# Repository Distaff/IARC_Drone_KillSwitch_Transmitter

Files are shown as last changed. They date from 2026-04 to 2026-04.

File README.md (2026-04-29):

# Killswitch for IARC Hat for CMDB
## PCB Design

Board layout:
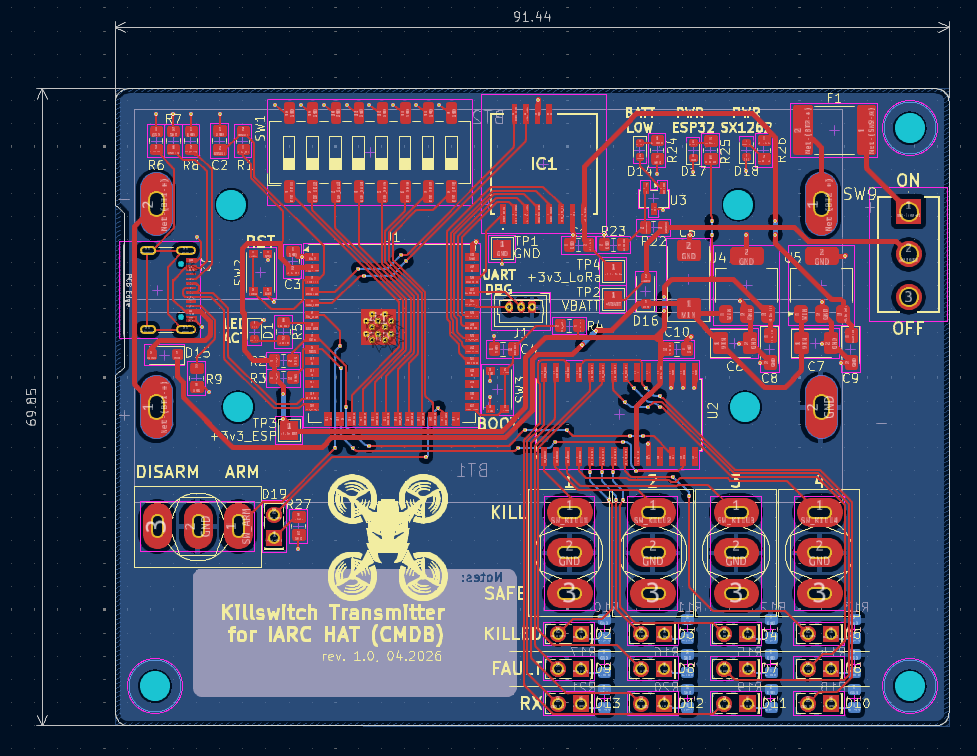
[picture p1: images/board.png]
Board layout


3D render:
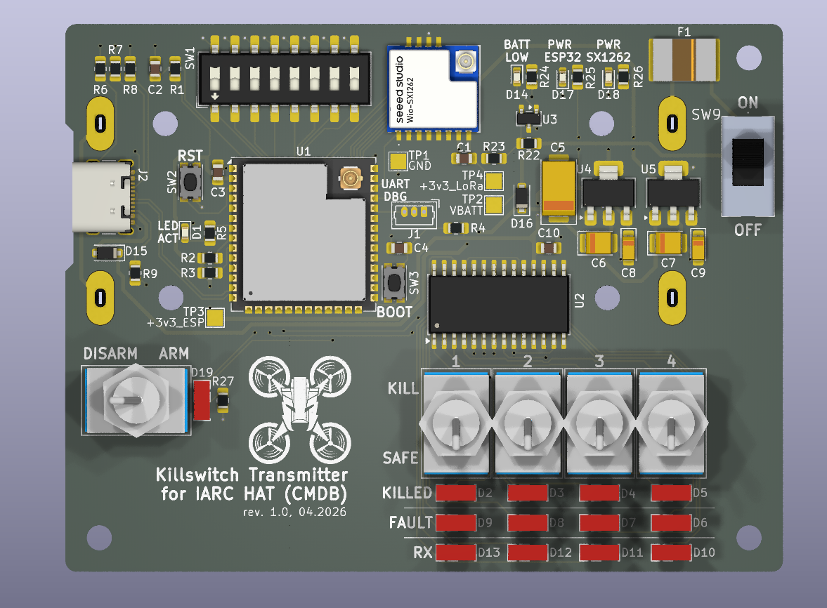
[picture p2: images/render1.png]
3D render front 3D render - front

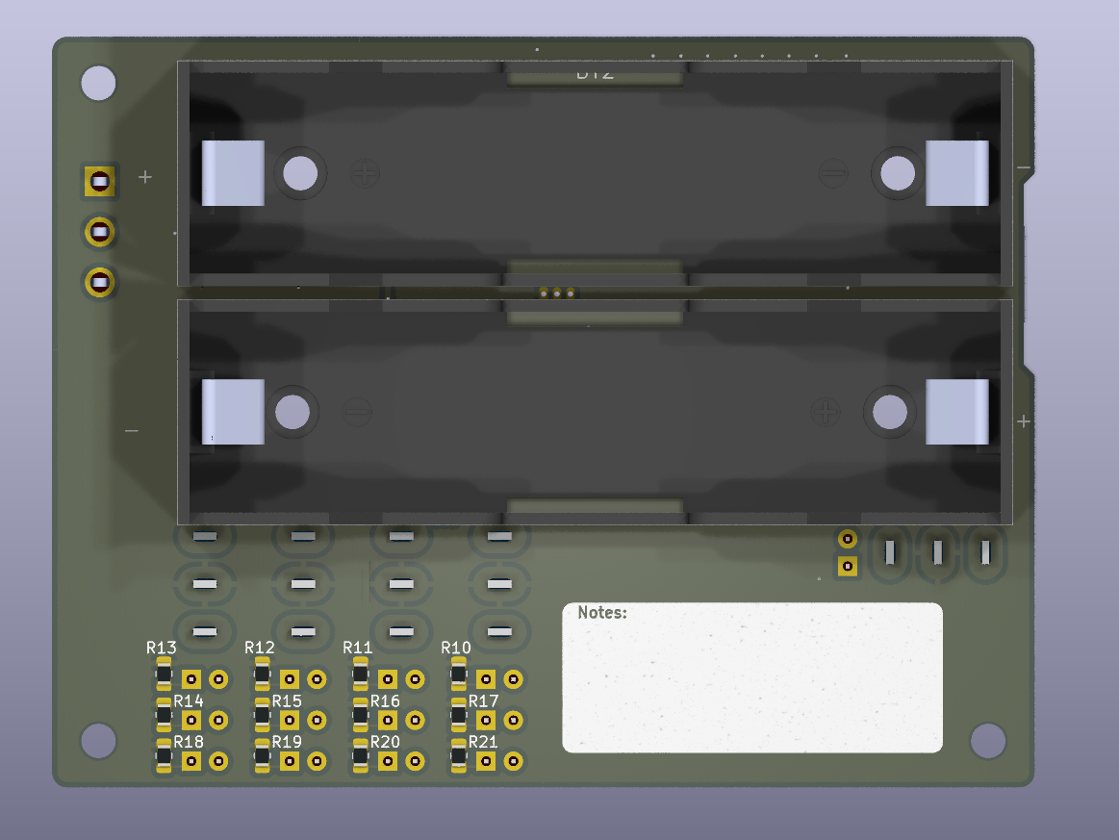
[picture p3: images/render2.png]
3D render back 3D render - back


## Usage
- Broadcast killing signal for drones using IARC CMDB hat or other LoRa-based killswitch
- Serve as LoRa packet grabber (by connecting to PC through UART

Board can be powered either from 2x 18650 cells or directly from USB-C (if host provides enough power).
No built-in undervoltage protection circuit is present, except for a warning LED.

## Authors
- Szymon Konopka (PCB Design)
- Piotr Kądziela (schematic design and PCB review)

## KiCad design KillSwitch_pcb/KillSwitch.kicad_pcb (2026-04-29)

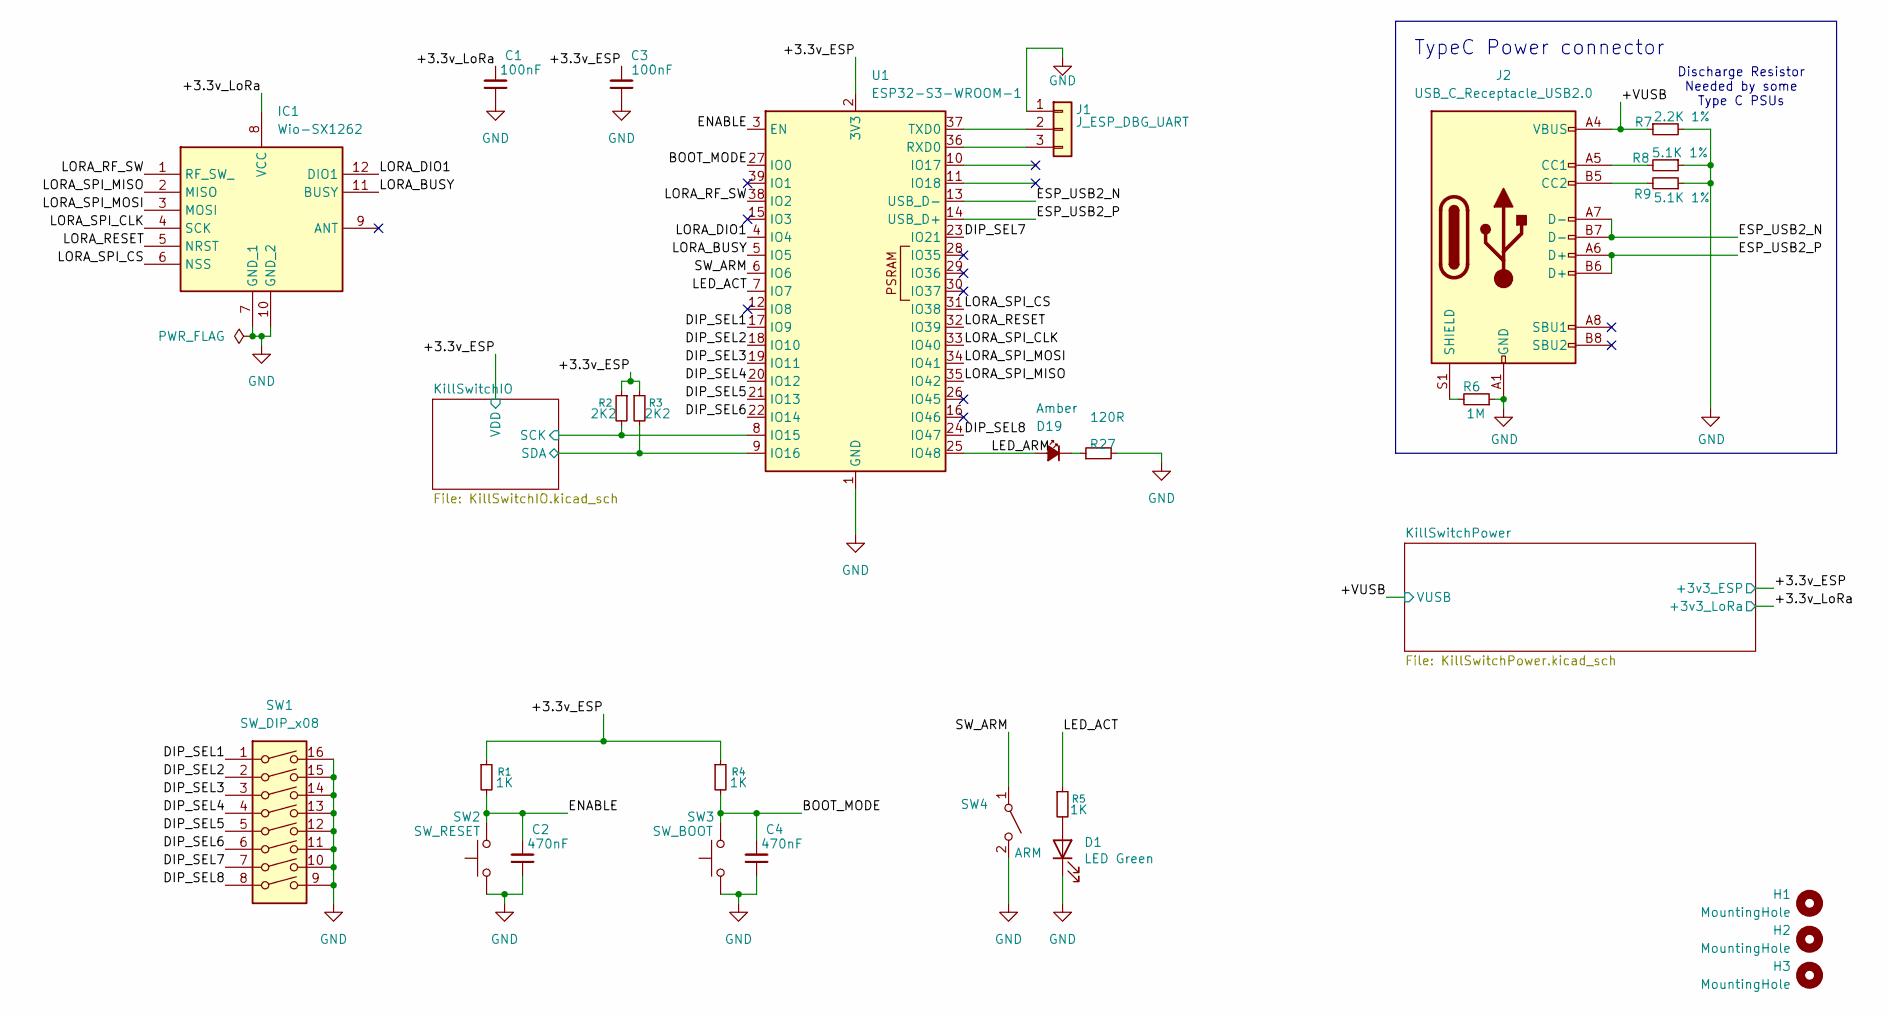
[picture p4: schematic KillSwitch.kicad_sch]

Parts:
C1, C3: 100nF; C_0805_2012Metric_Pad1.18x1.45mm_HandSolder
C2, C4: 470nF; C_0805_2012Metric_Pad1.18x1.45mm_HandSolder
D1: LED Green; LED_0603_1608Metric; Part Description Green 572nm LED Indication - Discrete 2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
D19: Amber; LED_Rectangular_W5.0mm_H2.0mm
H1, H2, H3: MountingHole; MountingHole_3.2mm_M3_DIN965
IC1: Wio-SX1262; Mouser Part Number 713-114993390
J1: J_ESP_DBG_UART; Molex_PicoBlade_53047-0310_1x03_P1.25mm_Vertical; Part Description Pin Header, Vertical, Signal, Wire-to-B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
J2: USB_C_Receptacle_USB2.0; USB_C_Receptacle_GCT_USB4105-xx-A_16P_TopMnt_Horizontal; Part Description USBC USB2 data and power connector
R1, R4, R5: 1K; R_0805_2012Metric_Pad1.20x1.40mm_HandSolder
R2, R3: 2K2; R_0805_2012Metric_Pad1.20x1.40mm_HandSolder
R6: 1M; R_0805_2012Metric_Pad1.20x1.40mm_HandSolder; Part Description Resistor 5.1K 1% 63mW
R7: 2.2K 1%; R_0805_2012Metric_Pad1.20x1.40mm_HandSolder; Part Description Resistor 2.2K 1% 63mW
R8, R9: 5.1K 1%; R_0805_2012Metric_Pad1.20x1.40mm_HandSolder; Part Description Resistor 5.1K 1% 63mW
R27: 120R; R_0805_2012Metric_Pad1.20x1.40mm_HandSolder
SW1: SW_DIP_x08; SW_DIP_SPSTx08_Slide_6.7x21.88mm_W8.61mm_P2.54mm_LowProfile
SW2: SW_RESET; SW_Push_1P1T_NO_CK_KMR2; Part Description Tactile Switch, KMR 2 Series, Top Actua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
SW3: SW_BOOT; SW_Push_1P1T_NO_CK_KMR2; Part Description Tactile Switch, KMR 2 Series, Top Actua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
SW4: ARM; SW_Toggle_Blue_wSlots
U1: ESP32-S3-WROOM-1; ESP32-S3-WROOM-1U

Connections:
/+3.3v_ESP: C3.2, R1.1, R2.1, R3.1, R4.1, U1.2 (3V3); also elsewhere on the board
/+3.3v_LoRa: C1.2, IC1.8 (VCC); also elsewhere on the board
/+VUSB: J2.A4 (VBUS), J2.A9 (VBUS), J2.B4 (VBUS), J2.B9 (VBUS), R7.1; also elsewhere on the board
/BOOT_MODE: C4.2, R4.2, SW3.2, U1.27 (IO0)
/DIP_SEL1: SW1.1, U1.17 (IO9)
/DIP_SEL2: SW1.2, U1.18 (IO10)
/DIP_SEL3: SW1.3, U1.19 (IO11)
/DIP_SEL4: SW1.4, U1.20 (IO12)
/DIP_SEL5: SW1.5, U1.21 (IO13)
/DIP_SEL6: SW1.6, U1.22 (IO14)
/DIP_SEL7: SW1.7, U1.23 (IO21)
/DIP_SEL8: SW1.8, U1.24 (IO47)
/ENABLE: C2.2, R1.2, SW2.2, U1.3 (EN)
/ESP_USB2_N: J2.A7 (D-), J2.B7 (D-), U1.13 (USB_D-)
/ESP_USB2_P: J2.A6 (D+), J2.B6 (D+), U1.14 (USB_D+)
/KillSwitchIO/SCK: R2.2, U1.8 (IO15); also elsewhere on the board
/KillSwitchIO/SDA: R3.2, U1.9 (IO16); also elsewhere on the board
/LED_ACT: R5.1, U1.7 (IO7)
/LED_ARM: D19.2 (A), U1.25 (IO48)
/LORA_BUSY: IC1.11 (BUSY), U1.5 (IO5)
/LORA_DIO1: IC1.12 (DIO1), U1.4 (IO4)
/LORA_RESET: IC1.5 (NRST), U1.32 (IO39)
/LORA_RF_SW: IC1.1 (RF_SW_), U1.38 (IO2)
/LORA_SPI_CLK: IC1.4 (SCK), U1.33 (IO40)
/LORA_SPI_CS: IC1.6 (NSS), U1.31 (IO38)
/LORA_SPI_MISO: IC1.2 (MISO), U1.35 (IO42)
/LORA_SPI_MOSI: IC1.3 (MOSI), U1.34 (IO41)
/SW_ARM: SW4.1 (A), U1.6 (IO6)
GND: C1.1, C2.1, C3.1, C4.1, D1.1 (K), IC1.7 (GND_1), IC1.10 (GND_2), J1.1, J2.A1 (GND), J2.A12 (GND), J2.B1 (GND), J2.B12 (GND), R6.1, R7.2, R8.1, R9.1, R27.2, SW1.9, SW1.10, SW1.11, SW1.12, SW1.13, SW1.14, SW1.15, SW1.16, SW2.1, SW3.1, SW4.2 (B), U1.1 (GND), U1.40 (GND), U1.41 (GND); also elsewhere on the board
unnamed: D1.2 (A), R5.2
unnamed: D19.1 (K), R27.1
unnamed: J1.2, U1.37 (TXD0)
unnamed: J1.3, U1.36 (RXD0)
unnamed: J2.A5 (CC1), R8.2
unnamed: J2.B5 (CC2), R9.2
unnamed: J2.S1 (SHIELD), R6.2

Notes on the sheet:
Discharge Resistor Needed by some Type C PSUs
TypeC Power connector

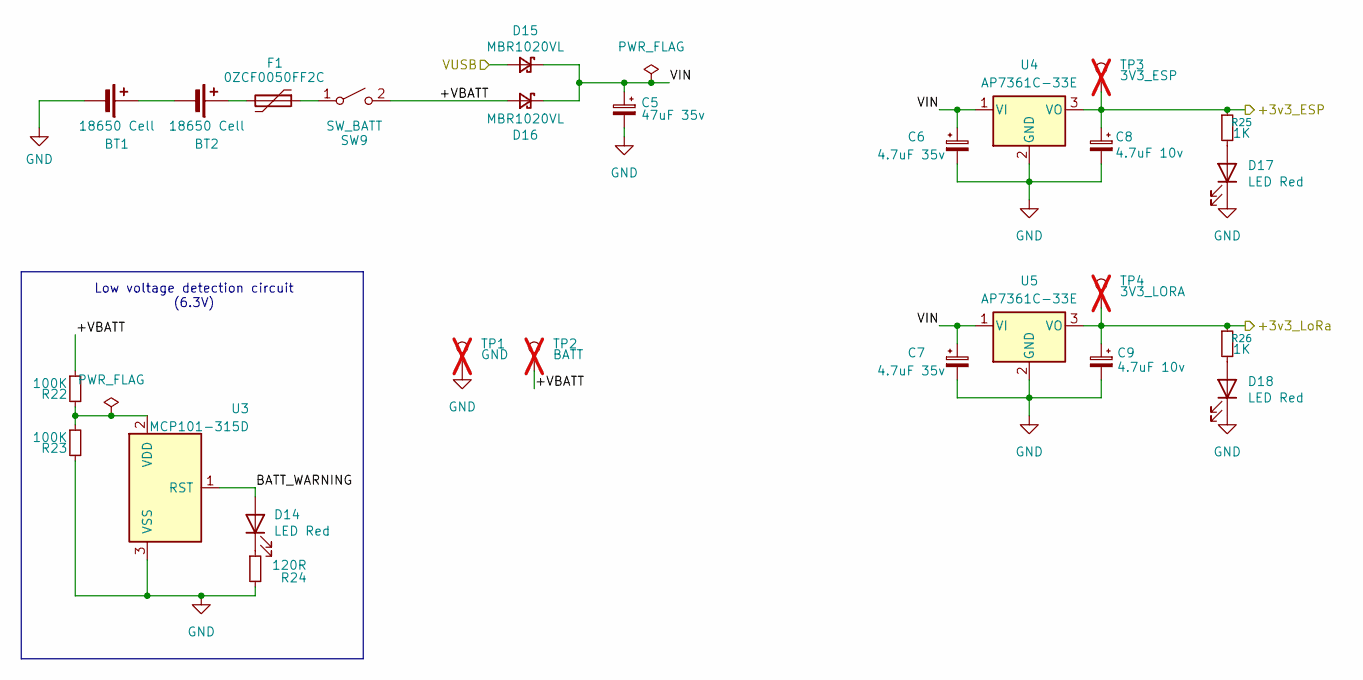
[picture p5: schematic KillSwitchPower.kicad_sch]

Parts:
BT1, BT2: 18650 Cell; BAT_BH-18650-PC
C5: 47uF 35v; CP_EIA-7343-31_Kemet-D_HandSolder
C6, C7: 4.7uF 35v; CP_EIA-3528-21_Kemet-B_HandSolder
C8, C9: 4.7uF 10v; CP_EIA-3216-18_Kemet-A_HandSolder
D14, D17, D18: LED Red; LED_0603_1608Metric; Part Description Red 620nm LED Indication - Discrete 2.2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
D15, D16: MBR1020VL; D_SOD-123F
F1: 0ZCF0050FF2C; Fuse_2920_7451Metric_Pad2.10x5.45mm_HandSolder
R22, R23: 100K; R_0805_2012Metric_Pad1.20x1.40mm_HandSolder
R24: 120R; R_0805_2012Metric_Pad1.20x1.40mm_HandSolder
R25, R26: 1K; R_0805_2012Metric_Pad1.20x1.40mm_HandSolder
SW9: SW_BATT; SL19121
TP1: GND; TestPoint_Pad_2.0x2.0mm; Part Description Test point; not fitted
TP2: BATT; TestPoint_Pad_2.0x2.0mm; Part Description Test point; not fitted
TP3: 3V3_ESP; TestPoint_Pad_2.0x2.0mm; Part Description Test point; not fitted
TP4: 3V3_LORA; TestPoint_Pad_2.0x2.0mm; Part Description Test point; not fitted
U3: MCP101-315D; SOT-23-3
U4, U5: AP7361C-33E; SOT-223-3_TabPin2; Part Description LDO, FIXED, 3.3V, 1A, -40 TO 85DEG C

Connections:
/+3.3v_ESP: C8.1, R25.1, TP3.1, U4.3 (VO); also elsewhere on the board
/+3.3v_LoRa: C9.1, R26.1, TP4.1, U5.3 (VO); also elsewhere on the board
/+VUSB: D15.2 (A); also elsewhere on the board
/KillSwitchPower/+VBATT: D16.2 (A), R22.1, SW9.2 (B), TP2.1
/KillSwitchPower/BATT_WARNING: D14.2 (A), U3.1 (RST)
/KillSwitchPower/VIN: C5.1, C6.1, C7.1, D15.1 (K), D16.1 (K), U4.1 (VI), U5.1 (VI)
GND: BT1.2 (-), C5.2, C6.2, C7.2, C8.2, C9.2, D17.1 (K), D18.1 (K), R23.2, R24.2, TP1.1, U3.3 (VSS), U4.2 (GND), U5.2 (GND); also elsewhere on the board
unnamed: BT1.1 (+), BT2.2 (-)
unnamed: BT2.1 (+), F1.2
unnamed: D14.1 (K), R24.1
unnamed: D17.2 (A), R25.2
unnamed: D18.2 (A), R26.2
unnamed: F1.1, SW9.1 (A)
unnamed: R22.2, R23.1, U3.2 (VDD)

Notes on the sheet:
Low voltage detection circuit (6.3V)

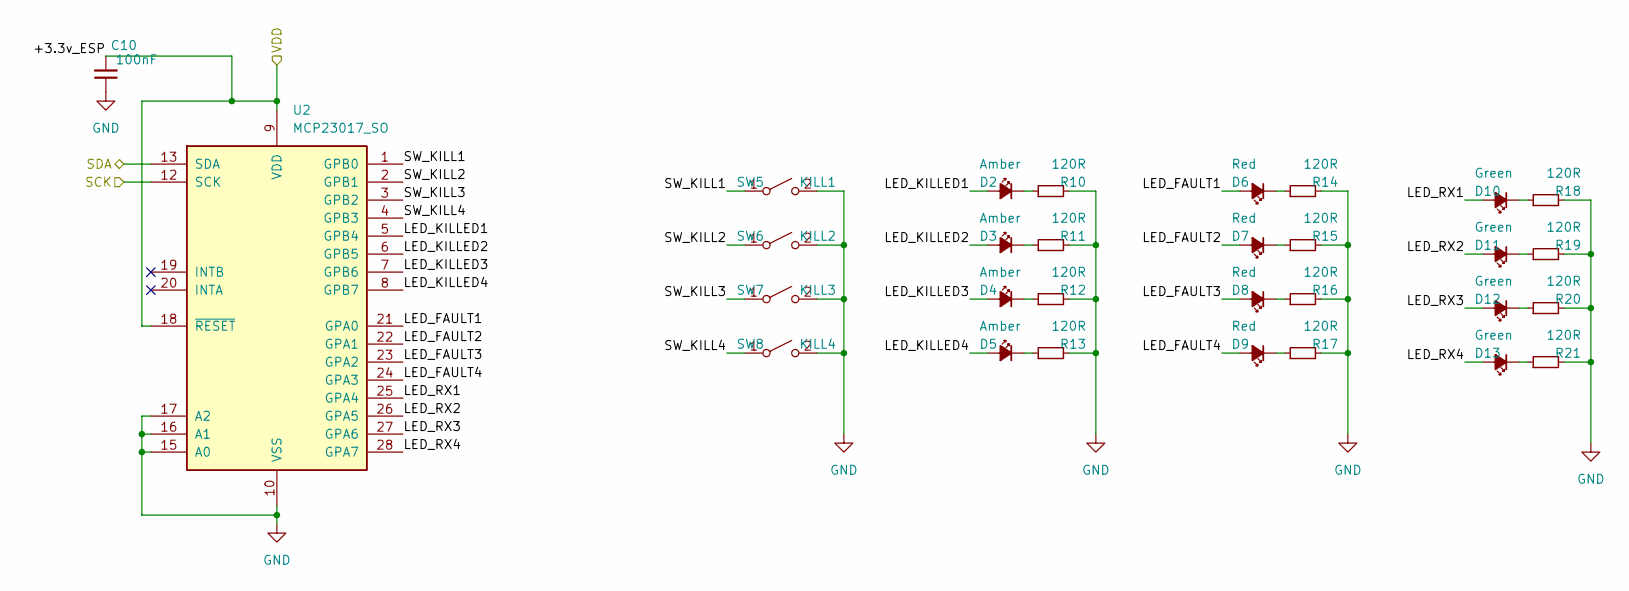
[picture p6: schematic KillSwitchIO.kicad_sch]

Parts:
C10: 100nF; C_0805_2012Metric_Pad1.18x1.45mm_HandSolder
D2, D3, D4, D5: Amber; LED_Rectangular_W5.0mm_H2.0mm
D6, D7, D8, D9: Red; LED_Rectangular_W5.0mm_H2.0mm
D10, D11, D12, D13: Green; LED_Rectangular_W5.0mm_H2.0mm
R10, R11, R12, R13, R14, R15, R16, R17, R18, R19, R20, R21: 120R; R_0805_2012Metric_Pad1.20x1.40mm_HandSolder
SW5: KILL1; SW_Toggle_Blue_wSlots
SW6: KILL2; SW_Toggle_Blue_wSlots
SW7: KILL3; SW_Toggle_Blue_wSlots
SW8: KILL4; SW_Toggle_Blue_wSlots
U2: MCP23017_SO; SOIC-28W_7.5x17.9mm_P1.27mm

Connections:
/+3.3v_ESP: C10.2, U2.9 (VDD), U2.18 (~RESET); also elsewhere on the board
/KillSwitchIO/LED_FAULT1: D6.2 (A), U2.21 (GPA0)
/KillSwitchIO/LED_FAULT2: D7.2 (A), U2.22 (GPA1)
/KillSwitchIO/LED_FAULT3: D8.2 (A), U2.23 (GPA2)
/KillSwitchIO/LED_FAULT4: D9.2 (A), U2.24 (GPA3)
/KillSwitchIO/LED_KILLED1: D2.2 (A), U2.5 (GPB4)
/KillSwitchIO/LED_KILLED2: D3.2 (A), U2.6 (GPB5)
/KillSwitchIO/LED_KILLED3: D4.2 (A), U2.7 (GPB6)
/KillSwitchIO/LED_KILLED4: D5.2 (A), U2.8 (GPB7)
/KillSwitchIO/LED_RX1: D10.2 (A), U2.25 (GPA4)
/KillSwitchIO/LED_RX2: D11.2 (A), U2.26 (GPA5)
/KillSwitchIO/LED_RX3: D12.2 (A), U2.27 (GPA6)
/KillSwitchIO/LED_RX4: D13.2 (A), U2.28 (GPA7)
/KillSwitchIO/SCK: U2.12 (SCK); also elsewhere on the board
/KillSwitchIO/SDA: U2.13 (SDA); also elsewhere on the board
/KillSwitchIO/SW_KILL1: SW5.1 (A), U2.1 (GPB0)
/KillSwitchIO/SW_KILL2: SW6.1 (A), U2.2 (GPB1)
/KillSwitchIO/SW_KILL3: SW7.1 (A), U2.3 (GPB2)
/KillSwitchIO/SW_KILL4: SW8.1 (A), U2.4 (GPB3)
GND: C10.1, R10.2, R11.2, R12.2, R13.2, R14.2, R15.2, R16.2, R17.2, R18.2, R19.2, R20.2, R21.2, SW5.2 (B), SW6.2 (B), SW7.2 (B), SW8.2 (B), U2.10 (VSS), U2.15 (A0), U2.16 (A1), U2.17 (A2); also elsewhere on the board
unnamed: D2.1 (K), R10.1
unnamed: D3.1 (K), R11.1
unnamed: D4.1 (K), R12.1
unnamed: D5.1 (K), R13.1
unnamed: D6.1 (K), R14.1
unnamed: D7.1 (K), R15.1
unnamed: D8.1 (K), R16.1
unnamed: D9.1 (K), R17.1
unnamed: D10.1 (K), R18.1
unnamed: D11.1 (K), R19.1
unnamed: D12.1 (K), R20.1
unnamed: D13.1 (K), R21.1

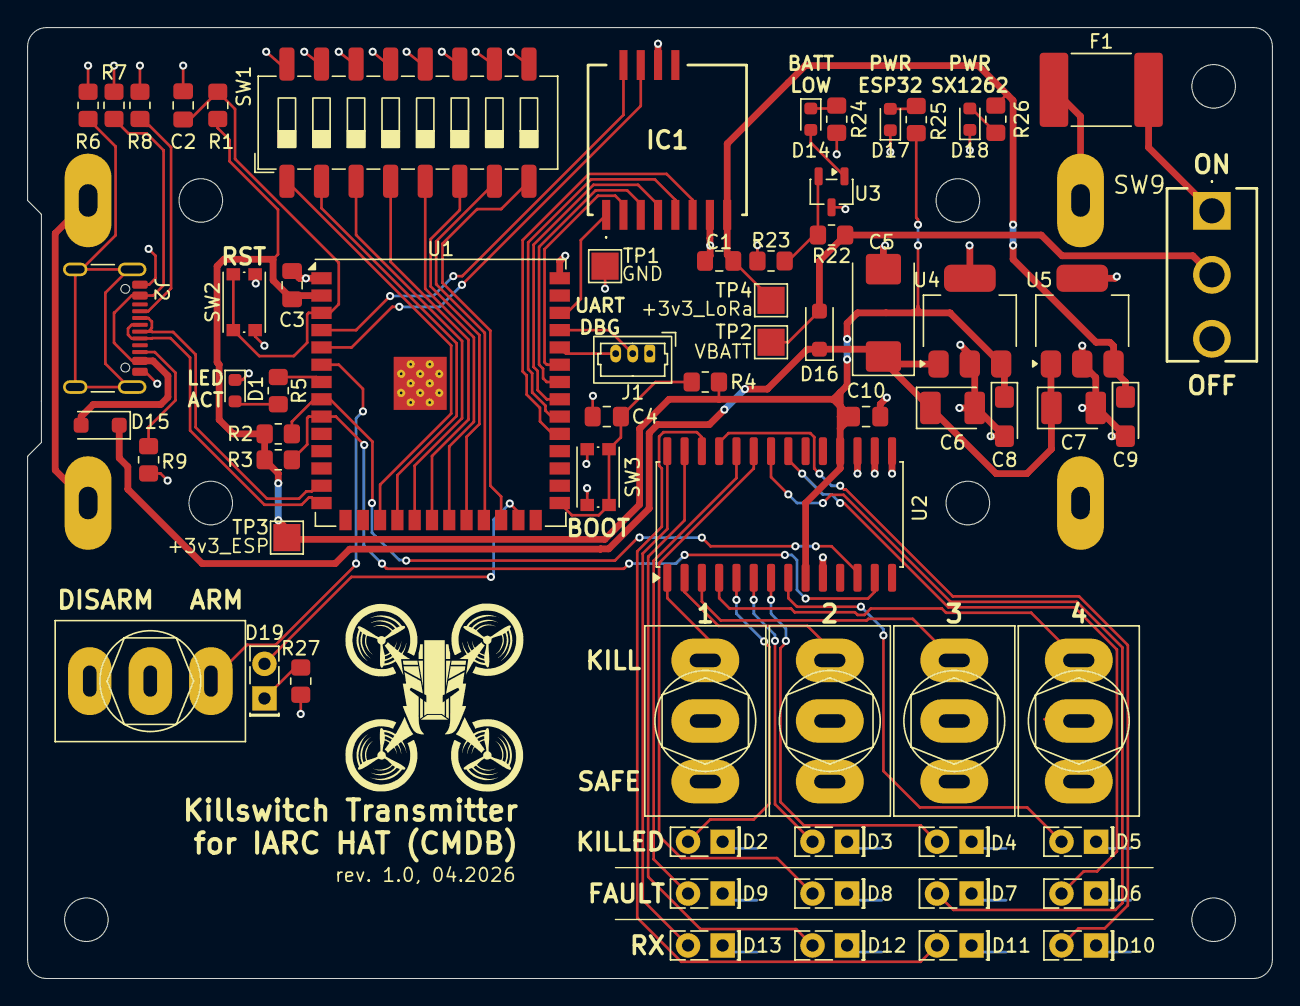
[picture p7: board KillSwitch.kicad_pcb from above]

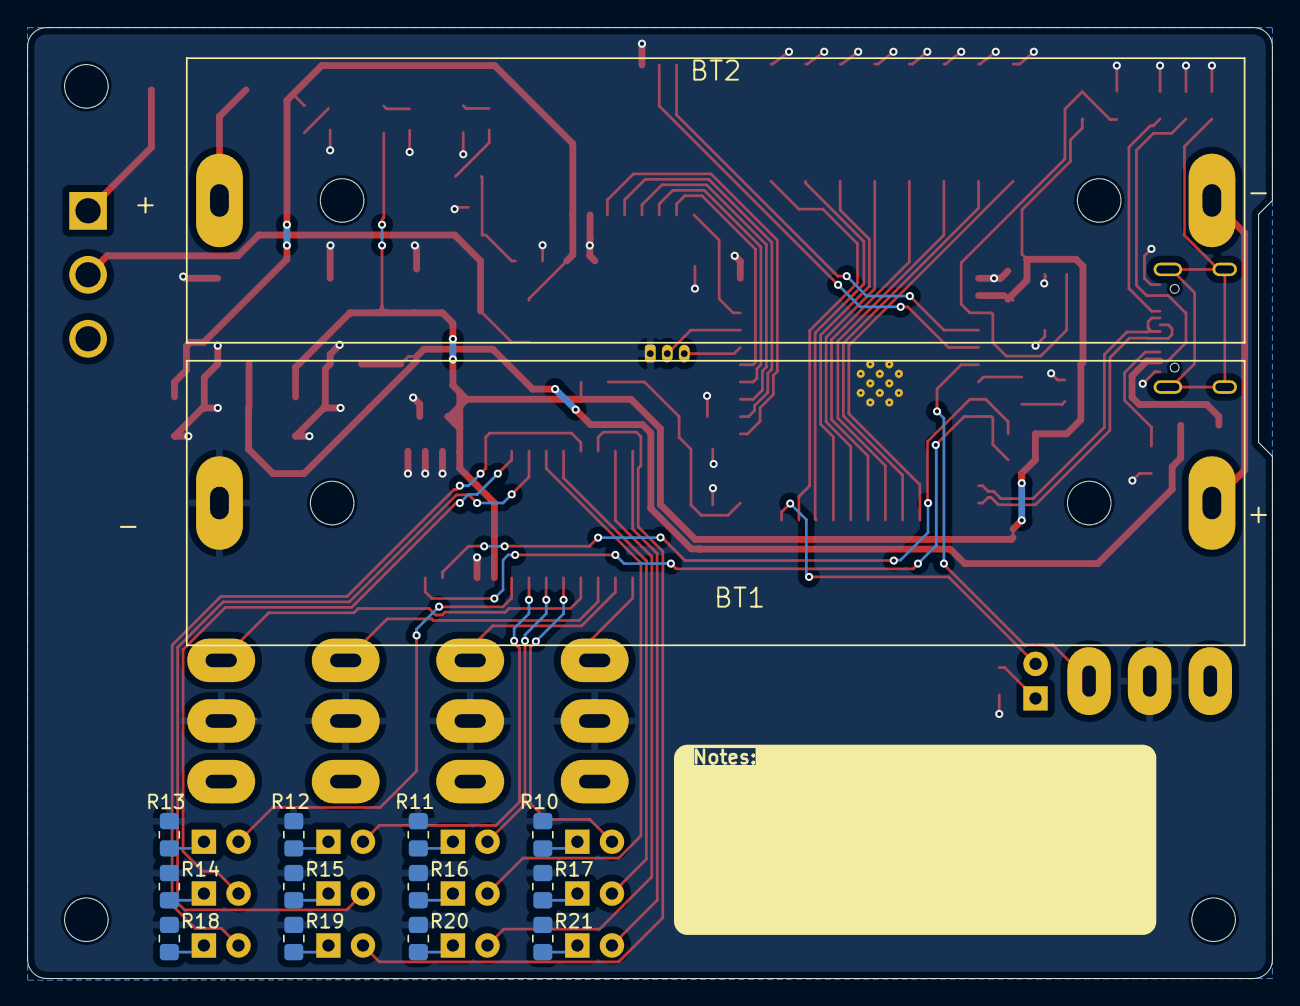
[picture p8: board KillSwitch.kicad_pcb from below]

Board: 2 copper layers, 91.4 x 69.8 mm, 83 parts (14 on the bottom side), 74 nets.

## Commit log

2026-04-15 move files into pcb directory
    [KillSwitch.kicad_pcb, KillSwitch.kicad_sch, KillSwitchIO.kicad_sch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]
2026-04-15 add pullups for i2c, reannotate, update footprints
    [KillSwitch.kicad_pcb, KillSwitch.kicad_sch, KillSwitchIO.kicad_sch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]
